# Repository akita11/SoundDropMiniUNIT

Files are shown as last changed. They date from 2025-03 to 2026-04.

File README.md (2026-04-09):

# SoundDropMiniUNIT

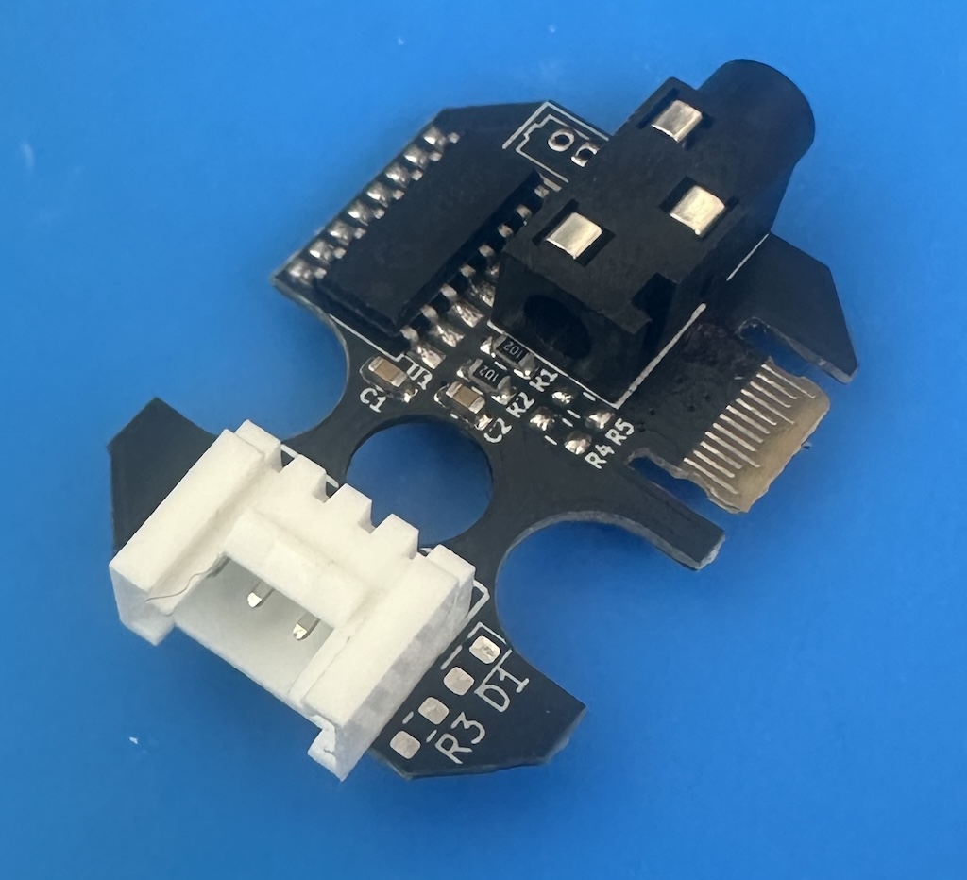
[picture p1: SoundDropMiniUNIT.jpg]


音声再生IC CH7800を使用した音声再生モジュールです。300KBのフラッシュメモリを搭載しており、PCにUSB Type-Cケーブルで接続するとUSBメモリとして認識され、そこにMP3音声データ等をコピーします。その音声データをGrove端子のシリアル(UART)通信で再生制御できます。UIFlow(v1)用のブロックもあります。

※CH7800に関する情報はWebページ等で検索してください。要点は以下にまとめてあります。

## 使い方（接続方法）

以下のようにスピーカやアンプを接続し、Grove端子からの制御で音声を再生します。
あわせて後述のcofig.txtでスピーカ出力（5文字目を"1"とする）に設定します（初期設定状態）。

### アンプ付きスピーカに接続する場合

3.5mmジャック（ステレオ：上部中央）に3.5mmステレオケーブル等でアンプに接続します。
あわせて後述のcofig.txtでDAC出力（5文字目を"0"とする）に設定します。

### スピーカを直接接続する場合

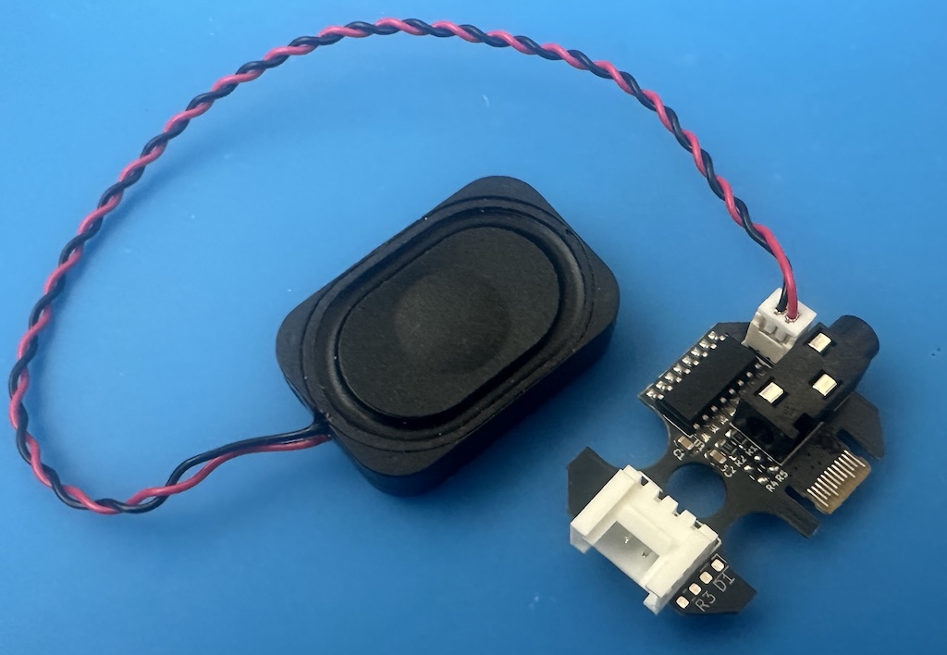
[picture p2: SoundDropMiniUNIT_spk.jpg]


基板上部にある1.25mmピッチコネクタ(Molex 53047-0210用)をとりつける端子があり、市販の小型スピーカ（M5Stack本体に使われているものなど。AliExpressやTaobaoでも同等品があります）を接続することができます。※隙間がせまく差し込みにくいので注意してください。
あわせて後述のcofig.txtでスピーカ出力（5文字目を"1"とする）に設定します（初期設定状態）。

### 3.5mmジャックに直接スピーカを接続する方法

3.5mmジャックに直接スピーカを接続することもできます。その場合は、基板裏面のハンダジャンパを以下のように修正してください。（スピーカはモノラル再生となります）
※結線は、プラグの根本側から、GND-SPK-NC(無接続)、の順となります。そのため、ステレオ型スピーカではL側からの再生になります。またモノラルプラグでは、このGNDとSPKが短絡されるため使用できません。

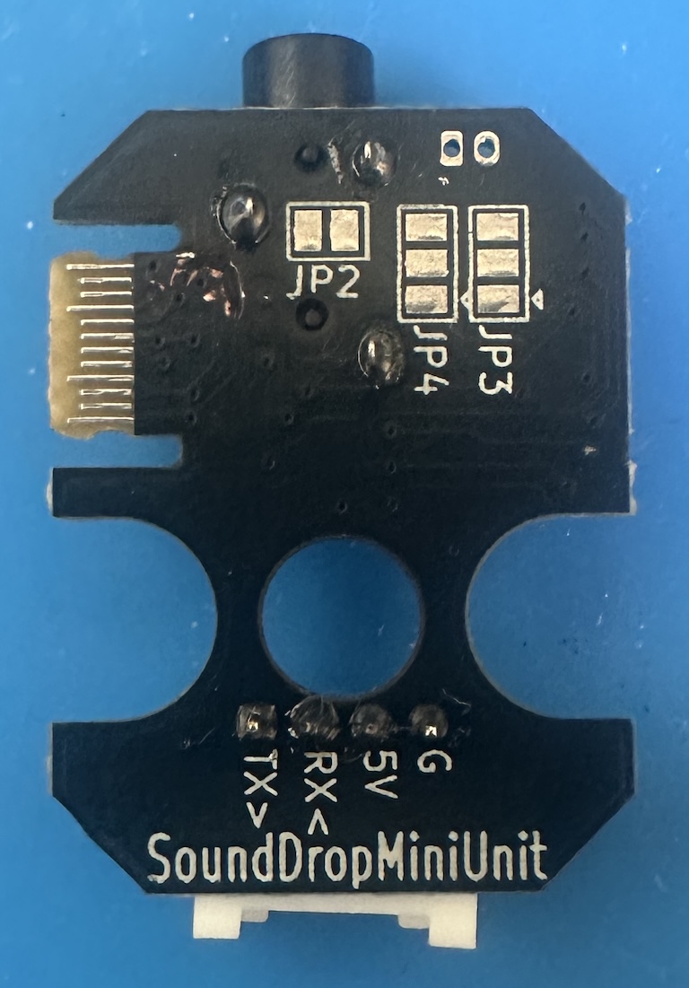
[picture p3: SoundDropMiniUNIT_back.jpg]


- JP2をカット
- JP3・JP4の中央と△マーク側をカットし、中央と反対側（△マークがない側）をショート

## 本体機能の設定

PC接続時に現れるドライブ内の"config.txt"で、以下の機能を指定できます。
設定情報は、config.txtの1行目に、以下の7桁の数値を記載します（それ以降は無視される）。
- 1文字目: ボタンの動作。0=再生中に中断可、1=再生中に中断不可、2=リピート再生1、3=リピート再生2、4=ON/OFF、5=常時リピート再生
- 2-3文字目: 音量(00-30)
- 4文字目: BUSY端子の機能(1=アクティブL、0=アクティブH)
- 5文字目: 出力(1=PWM(スピーカ)、0=DAC)
- 6文字目: ボタンの信号極性(0=アクティブL、1=アクティブH)
- 7文字目: 0=通常動作、1=低電力モード 

初期設定として"0300100"（音量30、スピーカ出力、など）となっています。

## 使い方（ソフトウエア）

あらかじめ、本体基板の一部にあるUSB Type-CにUSB Type-Cケーブルを使ってPCへ接続し、現れるドライブに使用する音声データ（*.mp3）をコピーしておきます。なおファイル名は、「"001"から"999"の3桁の数値」のみが有効（CH7800の仕様）となり、その数値が「曲番号」となります。

### UIFlow(v1)での使い方

「SoundDropMini.m5b」をダウンロードし、UIFlow(v1)の"Custom"の"Open *.m5b"からこのファイルを指定すると、Init、Play、Stopの3つのブロックを使用できます。

※(25/04/21)内容にミスがありました。現在の修正済みファイルを使ってください。

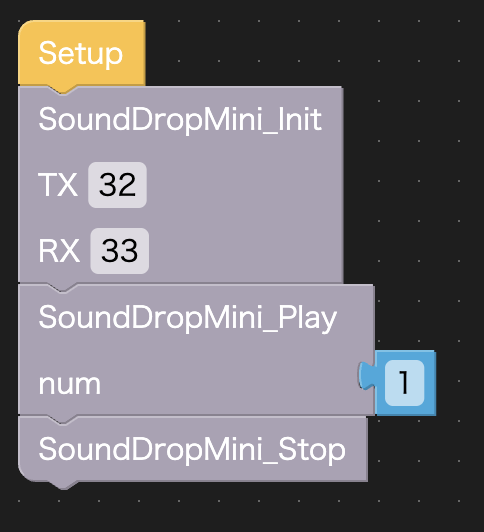
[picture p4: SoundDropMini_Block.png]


- SoundDropMini_Init : 初期化。最初に1回だけ使用します。"TX"と"RX"には、使用するGroveポート・マイコン本体にあわせて、使用するピン番号を指定します。例えば、M5StackBasicのPortA（本体の赤いコネクタ）の場合は、上図のようにTX=21、RX=22を指定します。M5StackCore2のPortAの場合は、TX=32、RX=33となります。
- SoundDropMini_Play : numに指定した「曲番号」の音声を再生します。
- SoundDropMini_Stop : 再生中の音声を停止します。

※この例では再生した直後に停止していますので、音声がほぼ聞こえません。実際には目的に合わせて使い分けてください。

### その他のソフトウエアでの使い方

搭載されている音声再生IC(CH7800)のデータシート等を参考に、制御コマンドをUART経由で送信して使用してください。通信プロトコルは「9600bps/N81」です。
制御コマンドの一部を以下にまとめます。

- 次の曲の再生: 0x7e 0x11 0x00 0x02 0x00 0x00 0xef
- 前の曲の再生: 0x7e 0x12 0x00 0x02 0x00 0x00 0xef
- 指定した曲(HH:LL＝曲番号(上位/下位の順))の再生: 0x7e 0x13 0x00 0x02 HH LL 0xef
- 音量UP: 7e 0x14 0x00 0x02 0x00 0x00 0xef
- 音量DOWN: 0x7e 0x15 0x00 0x02 0x00 0x00 0xef
- 音量をNNに設定: 0x7e 0x16 0x00 0x02 0x00 NN 0xef
- 再生停止: 0x7e 0x26 0x00 0x02 0x00 0x00 0xef

## Author

Junichi Akita (@akita11) / akita@ifdl.jp

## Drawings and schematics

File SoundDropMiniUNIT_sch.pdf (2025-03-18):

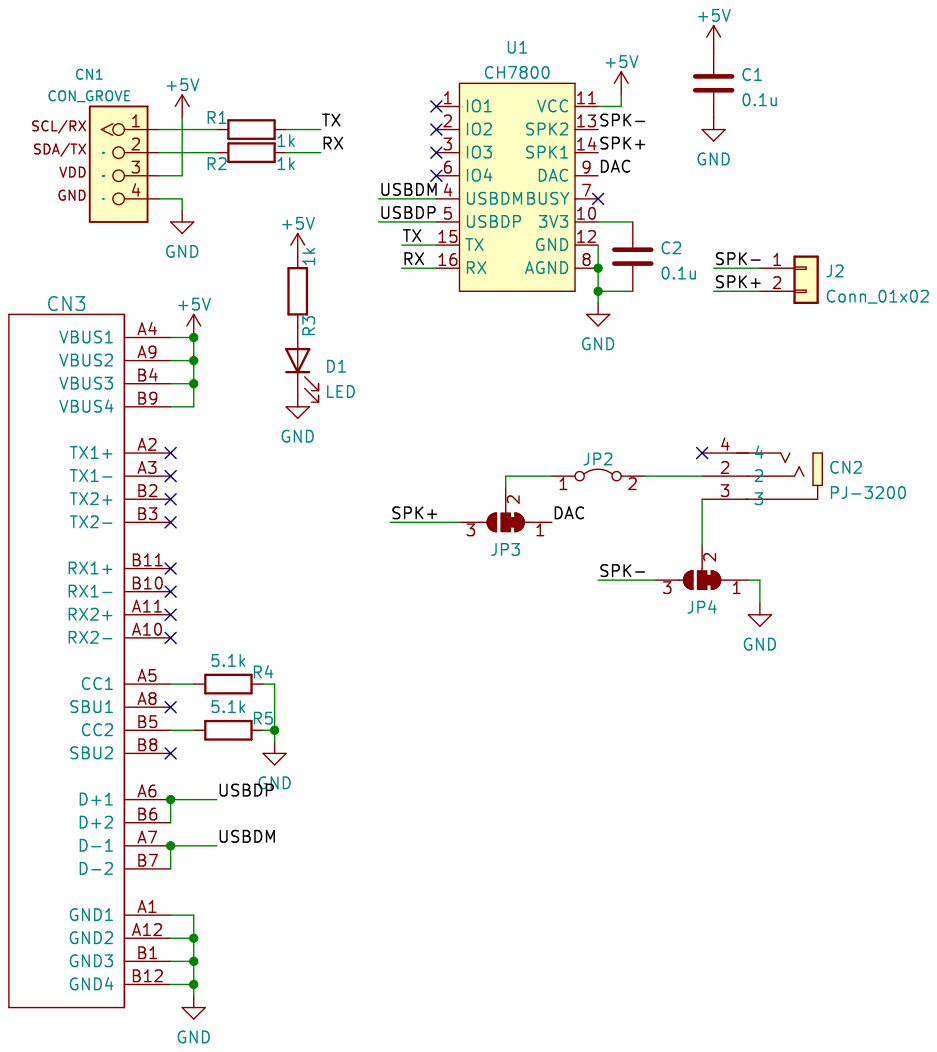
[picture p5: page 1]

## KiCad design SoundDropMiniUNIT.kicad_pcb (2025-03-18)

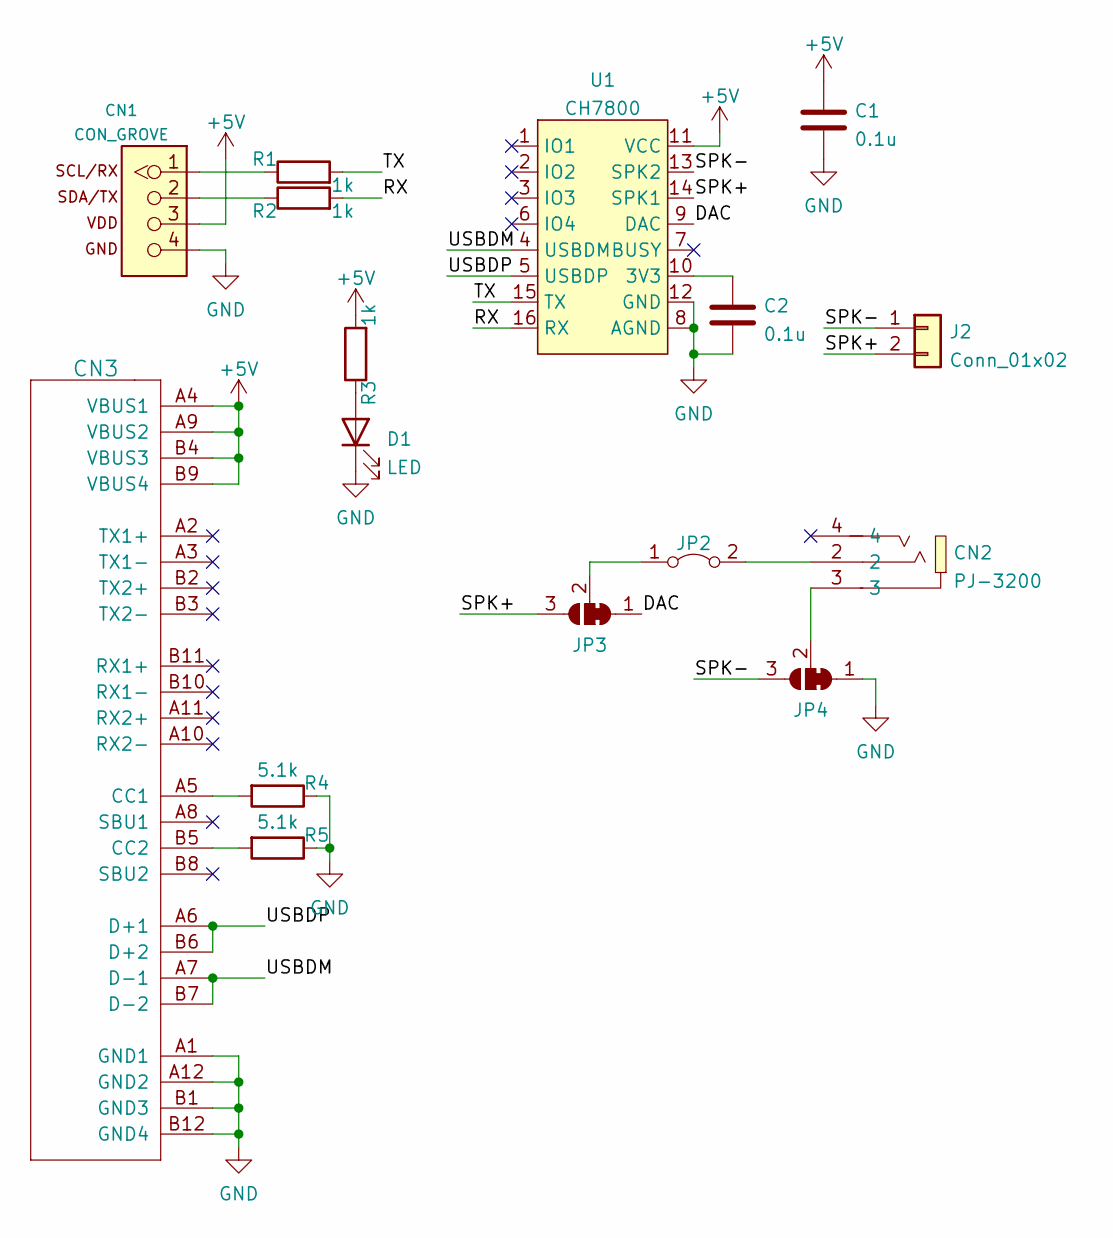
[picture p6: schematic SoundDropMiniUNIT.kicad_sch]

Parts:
C1, C2: 0.1u; C_0603_1608Metric
CN1: CON_GROVE; CON_GROVE_H
CN2: PJ-3200; AUDIO-TH_PJ-3200; LCSC Part C2689690
CN3: CON_USB-CPCBPLUG; USB-C_PCBPLUG
D1: LED; LED_0603_1608Metric
J2: Conn_01x02; Molex_PicoBlade_53047-0210_1x02_P1.25mm_Vertical
JP2: Jumper_2_Bridged; SolderJumper-2_P1.3mm_Bridged_Pad1.0x1.5mm
JP3, JP4: SolderJumper_3_Bridged12; SolderJumper-3_P1.3mm_Bridged12_Pad1.0x1.5mm
R1, R2, R3: 1k; R_0603_1608Metric
R4, R5: 5.1k; R_0603_1608Metric
U1: CH7800; SOP-16_4.4x10.4mm_P1.27mm

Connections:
+5V: C1.1, CN1.3, CN3.A4 (VBUS1), CN3.A9 (VBUS2), CN3.B4 (VBUS3), CN3.B9 (VBUS4), R3.2, U1.11 (VCC)
/DAC: JP3.1 (A), U1.9 (DAC)
/RX: R2.2, U1.16 (RX)
/SPK+: J2.2, JP3.3 (B), U1.14 (SPK1)
/SPK-: J2.1, JP4.3 (B), U1.13 (SPK2)
/TX: R1.2, U1.15 (TX)
/USBDM: CN3.A7 (D-1), CN3.B7 (D-2), U1.4 (USBDM)
/USBDP: CN3.A6 (D+1), CN3.B6 (D+2), U1.5 (USBDP)
GND: C1.2, C2.2, CN1.4, CN3.A1 (GND1), CN3.A12 (GND2), CN3.B1 (GND3), CN3.B12 (GND4), D1.1 (K), JP4.1 (A), R4.1, R5.1, U1.8 (AGND), U1.12 (GND)
unnamed: C2.1, U1.10 (3V3)
unnamed: CN1.1, R1.1
unnamed: CN1.2, R2.1
unnamed: CN2.2, JP2.2 (B)
unnamed: CN2.3, JP4.2 (C)
unnamed: CN3.A5 (CC1), R4.2
unnamed: CN3.B5 (CC2), R5.2
unnamed: D1.2 (A), R3.1
unnamed: JP2.1 (A), JP3.2 (C)

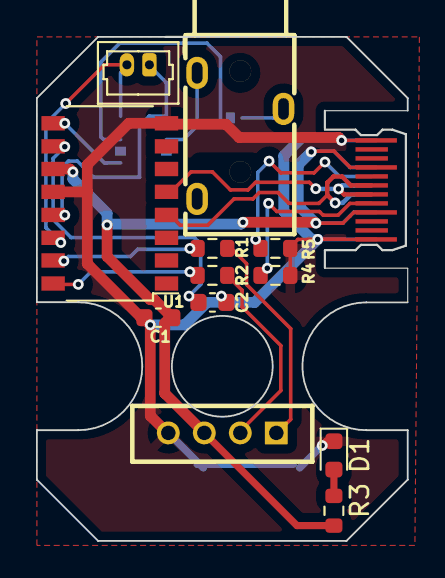
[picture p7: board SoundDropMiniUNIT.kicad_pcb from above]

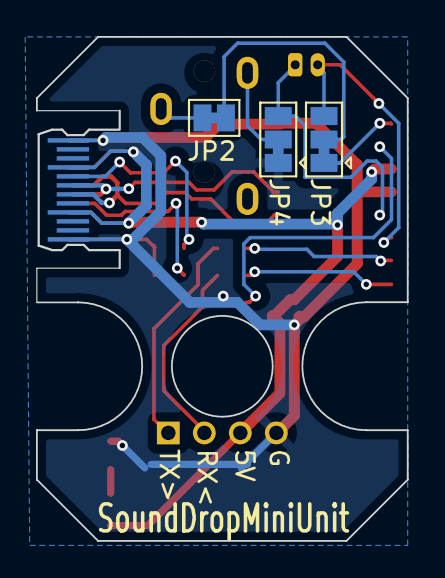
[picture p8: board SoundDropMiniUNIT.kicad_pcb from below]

Board: 2 copper layers, 20.6 x 28.0 mm, 16 parts (3 on the bottom side), 18 nets.

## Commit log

2025-03-18 intial commit, no photo
    [SoundDropMiniUNIT.kicad_pcb, SoundDropMiniUNIT.kicad_sch]
2026-04-09 Update README with speaker connection instructions
    Added instructions for connecting speakers directly to the 3.5mm jack.
